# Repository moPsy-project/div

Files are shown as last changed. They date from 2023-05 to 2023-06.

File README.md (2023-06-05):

# DIV

> Simple Counter/Divider Eurorack Module

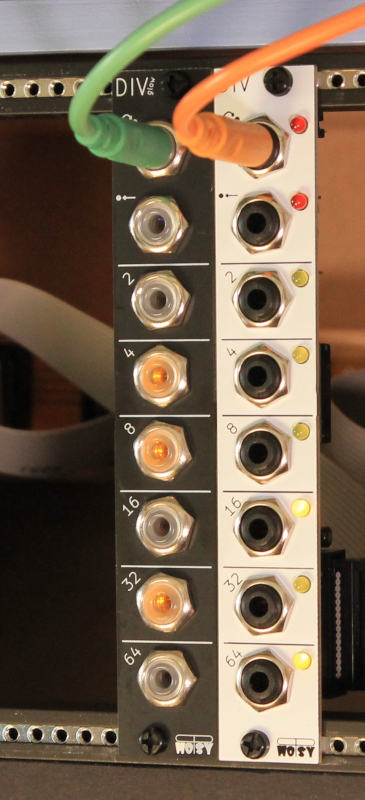
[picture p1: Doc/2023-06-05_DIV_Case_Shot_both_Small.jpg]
Front view of the DIV panel in a rack


## Dependencies

This project uses symbols from the [moPsy-KiCad-resources](https://github.com/moPsy-project/moPsy-KiCad-resources).

## License



This work is licensed under a [Creative Commons Attribution-ShareAlike 4.0 International License](http://creativecommons.org/licenses/by-sa/4.0/).

BY: Stefan Haun (mail@tuxathome.de)

See [LICENSE.txt](LICENSE.txt) for details.

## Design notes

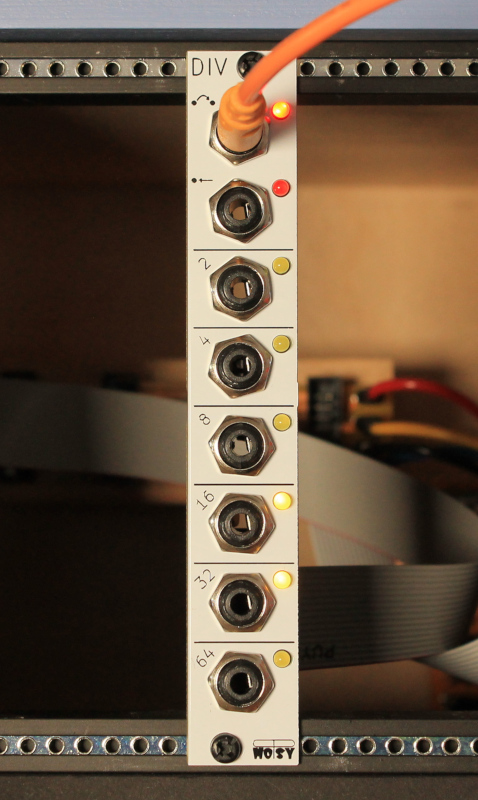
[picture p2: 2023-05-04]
Doc/2023-05-04_DIV_Case_Shot_Small.jpg

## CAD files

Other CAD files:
Frontpanel/div-outline.FCStd
Frontpanel/div-outline.dxf

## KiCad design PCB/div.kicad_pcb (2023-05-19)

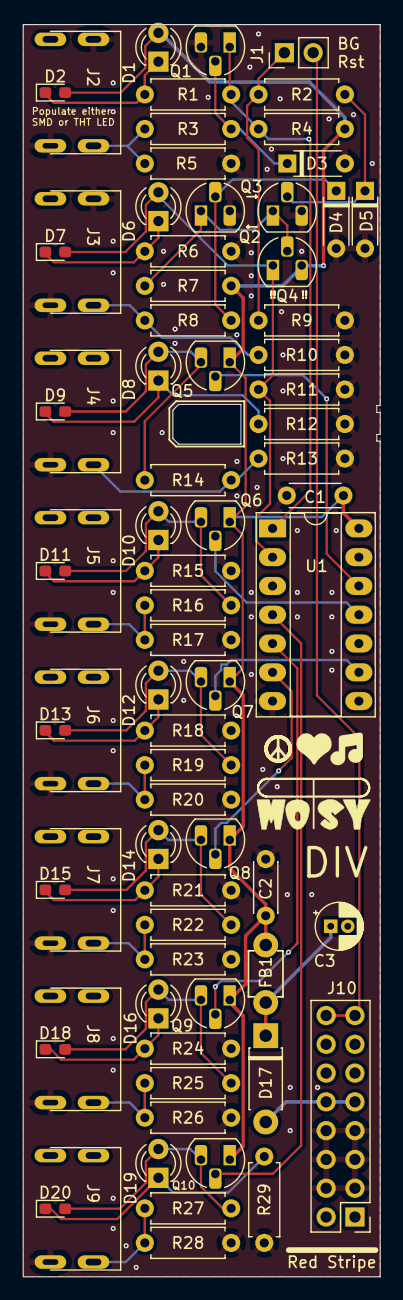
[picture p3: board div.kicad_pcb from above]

Board: 2 copper layers, 31.5 x 110.5 mm, 74 parts (0 on the bottom side), 40 nets.

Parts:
C1, C2: 100n; C_Disc_D4.3mm_W1.9mm_P5.00mm
C3: 10u; CP_Radial_D4.0mm_P1.50mm
D1: ye; LED_D3.0mm
D2, D7, D9, D11, D13, D15, D18, D20: gn; LED_0603_1608Metric_Pad1.05x0.95mm_HandSolder
D3, D4, D5: 1N4148; D_DO-35_SOD27_P5.08mm_Horizontal
D6: rt; LED_D3.0mm
D8, D10, D12, D14, D16, D19: gn; LED_D3.0mm
D17: 1N5817; D_DO-41_SOD81_P7.62mm_Horizontal
FB1: FerriteBead; FBeadL4D4
J1: Bus Gate Reset; PinHeader_1x02_P2.54mm_Vertical
J2: Clk; CLIFF 3.5mm S6 Mono Jack Socket
J3: Rst; CLIFF 3.5mm S6 Mono Jack Socket
J4, J5, J6, J7, J8, J9: OUT; CLIFF 3.5mm S6 Mono Jack Socket
J10: PWR; PinHeader_2x08_P2.54mm_Vertical
Q1, Q2, Q3, Q5, Q6, Q7, Q8, Q9, Q10: BC547; TO-92_HandSolder
Q4: BC557; TO-92_HandSolder
R1, R2, R3, R4, R6, R7, R8, R11, R12, R15, R18, R21, R24, R29: 10k; R_Axial_DIN0207_L6.3mm_D2.5mm_P7.62mm_Horizontal
R5, R9, R10: 1M; R_Axial_DIN0207_L6.3mm_D2.5mm_P7.62mm_Horizontal
R13, R14, R16, R17, R19, R20, R22, R23, R25, R26, R27, R28: 2k2; R_Axial_DIN0207_L6.3mm_D2.5mm_P7.62mm_Horizontal
U1: 4024; DIP-14_W7.62mm_Socket_LongPads

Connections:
+12V: C1.1, C2.1, D1.2 (A), D2.2 (A), FB1.2, Q4.3 (E), Q5.1 (C), Q6.1 (C), Q7.1 (C), Q8.1 (C), Q9.1 (C), Q10.1 (C), R4.2, R7.2, U1.14 (VDD)
/CLOCK_IN: Q1.1 (C), R1.1, R4.1, U1.1 (~CLK)
/Gate Output 2/GATE_OUT: Q5.2 (B), U1.12 (Q0)
/Gate Output 4/GATE_OUT: Q6.2 (B), U1.11 (Q1)
/Gate Output 8/GATE_OUT: Q7.2 (B), U1.9 (Q2)
/Gate Output 16/GATE_OUT: Q8.2 (B), U1.6 (Q3)
/Gate Output 32/GATE_OUT: Q9.2 (B), U1.5 (Q4)
/Gate Output 64/GATE_OUT: Q10.2 (B), U1.4 (Q5)
/RESET_IN: D6.2 (A), D7.2 (A), Q4.1 (C), R11.2, U1.2 (MR)
GND: C1.2, C2.2, C3.2, D3.2 (A), D4.2 (A), D5.2 (A), J2.S, J2.TN, J3.S, J3.TN, J4.S, J5.S, J6.S, J7.S, J8.S, J9.S, J10.3, J10.4, J10.5, J10.6, J10.7, J10.8, Q1.3 (E), Q2.3 (E), Q3.3 (E), R5.1, R6.1, R9.1, R10.1, R11.1, R12.1, R13.1, R15.1, R17.1, R18.1, R20.1, R21.1, R23.1, R24.1, R26.1, R28.1, R29.1, U1.7 (VSS)
Gate: J1.2, J10.15, J10.16
unnamed: D1.1 (K), D2.1 (K), R1.2
unnamed: D3.1 (K), Q1.2 (B), R3.2
unnamed: D4.1 (K), Q2.2 (B), R8.2
unnamed: D5.1 (K), Q3.2 (B), R2.2
unnamed: D6.1 (K), D7.1 (K), R6.2
unnamed: D8.2 (A), D9.2 (A), Q5.3 (E), R14.2
unnamed: D8.1 (K), D9.1 (K), R12.2
unnamed: D10.2 (A), D11.2 (A), Q6.3 (E), R16.2
unnamed: D10.1 (K), D11.1 (K), R15.2
unnamed: D12.2 (A), D13.2 (A), Q7.3 (E), R19.2
unnamed: D12.1 (K), D13.1 (K), R18.2
unnamed: D14.2 (A), D15.2 (A), Q8.3 (E), R22.2
unnamed: D14.1 (K), D15.1 (K), R21.2
unnamed: D16.2 (A), D18.2 (A), Q9.3 (E), R25.2
unnamed: D16.1 (K), D18.1 (K), R24.2
unnamed: D17.2 (A), J10.9, J10.10
unnamed: C3.1, D17.1 (K), FB1.1
unnamed: D19.2 (A), D20.2 (A), Q10.3 (E), R27.2
unnamed: D19.1 (K), D20.1 (K), R29.2
unnamed: J1.1, R2.1, R9.2
unnamed: J2.T, R3.1, R5.2
unnamed: J3.T, R8.1, R10.2
unnamed: J4.T, R13.2, R14.1
unnamed: J5.T, R16.1, R17.2
unnamed: J6.T, R19.1, R20.2
unnamed: J7.T, R22.1, R23.2
unnamed: J8.T, R25.1, R26.2
unnamed: J9.T, R27.1, R28.2
unnamed: Q2.1 (C), Q3.1 (C), Q4.2 (B), R7.1

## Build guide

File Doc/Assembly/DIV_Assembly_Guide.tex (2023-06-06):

\documentclass[a4paper,
               11pt,
               parskip=half,
               headinclude,
               titlepage=false]{scrartcl}

%%%%%%%%%%%%%%%%%%%%%%%%%%%%%%%%%%%%%%%%
\newcommand{\metaauthor}{moPsy}
\newcommand{\metatitle}{DIV Assembly Guide}
\newcommand{\metarev}{1.1}
%%%%%%%%%%%%%%%%%%%%%%%%%%%%%%%%%%%%%%%%

\usepackage[utf8]{inputenc}

\usepackage[T1]{fontenc}        % Tries to use Postscript Type 1 Fonts for better rendering
\usepackage{lmodern}            % Provides the Latin Modern Font which offers more glyphs than the default Computer Modern
\usepackage[sfdefault]{carlito}
\usepackage[intlimits]{amsmath} % Provides all mathematical commands
\usepackage[protrusion=true,
            expansion,
            kerning=true,
            babel=true]{microtype}
\usepackage{fontawesome}

\usepackage[english]{babel}
\usepackage[english]{isodate}

\usepackage{eurosym}
\usepackage[shortlabels]{enumitem}

\usepackage{grffile}            % Allow you to include images (like graphicx). Usage: \includegraphics{path/to/file}

\usepackage[ugly]{units}        % Allows you to type units with correct spacing and font style. Usage: $\unit[100]{m}$ or $\unitfrac[100]{m}{s}$

\usepackage{xspace}             % Use \xpsace in macros to automatically insert space based on context. Usage: \newcommand{\es}{ESPResSo\xspace}
\usepackage[dvipsnames,table]{xcolor}             % Obviously colors. Usage: \color{red} Red text
\usepackage{booktabs}           % Nice rules for tables. Usage \begin{tabular}\toprule ... \midrule ... \bottomrule

%\usepackage[hang]{subfigure}  % unterteilte Abbildungen
\usepackage{setspace}          %fuer dem Zeilanabstand
\usepackage[hang,bf,footnotesize]{caption}   % bessere Bildunterschriften
\usepackage{wrapfig}

\usepackage{csquotes}

\usepackage[hyphens]{url}                % Lets you typeset urls. Usage: \url{http://...}
\usepackage[pdftex,colorlinks=true,linkcolor=black,citecolor=black,urlcolor=black]{hyperref}
\hypersetup{
  pdftitle    = {\metatitle},
  pdfsubject  = {Assembly Guide},
  pdfauthor   = {\metaauthor},
  pdfkeywords = {} ,
  pdfcreator  = {pdflatex},
  pdfproducer = {LaTeX with hyperref}
}
%%%%%%%%%%%%%%%%%%%%%%%%%%%%%%%%%%%%%%%%

\usepackage{pdfpages}

\usepackage{tabularx}

\usepackage[headsepline, footsepline]{scrlayer-scrpage}
\setlength{\headheight}{34pt} % logo height
\clearpairofpagestyles
\ohead{
\vfill%
\begin{tabular}{@{}l l@{}}
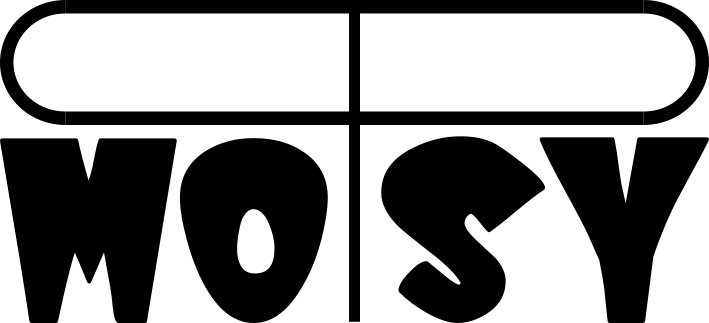
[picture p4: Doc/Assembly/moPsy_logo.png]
\hspace*{-0.1cm}
\end{tabular}
}
\ihead{
\vfill%
{\huge DIV} \,v\metarev\, Assembly Guide%
}
\ofoot{Page \thepage}
\setkomafont{pageheadfoot}{\sffamily\footnotesize}
\setkomafont{pagination}{}
\pagestyle{scrheadings}

%\usepackage{background}

%\usepackage[section]{placeins} % keep figures in their section

\definecolor{level_easy}{rgb}{0.2, 0.6, 0.1}

\definecolor{row1}{rgb}{1.0, 1.0, 1.0}
\definecolor{row2}{rgb}{0.93, 0.93, 0.99}

\begin{document}

\begin{minipage}{12.5cm}
\setlength{\parskip}{\medskipamount}
\section*{Thank you for choosing a  kit!}

\paragraph{tl;dr} Assembly is pretty straightforward. However, we strongly recommend soldering the transistors \emph{after} the LEDs to avoid Euclidean trouble.

This manual is meant to guide you through the assembly process.
We will point out common pitfalls when building this particular module.
Components are placed in an order that makes assembly as easy as possible.

The build is rated as {\color{level_easy}easy} and intended for {\color{level_easy}beginners}.
Still there may be bugs in the instructions or something may not be communicated optimally.
If you happen to get stuck or something is not clear, feel free to send us a message and we will do our best to sort things out.

You can reach us at \href{mailto:diy@mopsy-music.de}{\texttt{diy@mopsy-music.de}}.

Music is meant to be fun and we hope that you will enjoy building this module.
Please remember to take good care of yourself and get regular breaks whenever you start to feel exhausted. This is supposed to be an afternoon stroll, not a sprint for your life.

\vspace{1em}
Enjoy building! \quad 

\end{minipage}
\hspace{0.5cm}
\begin{minipage}{1.5cm}
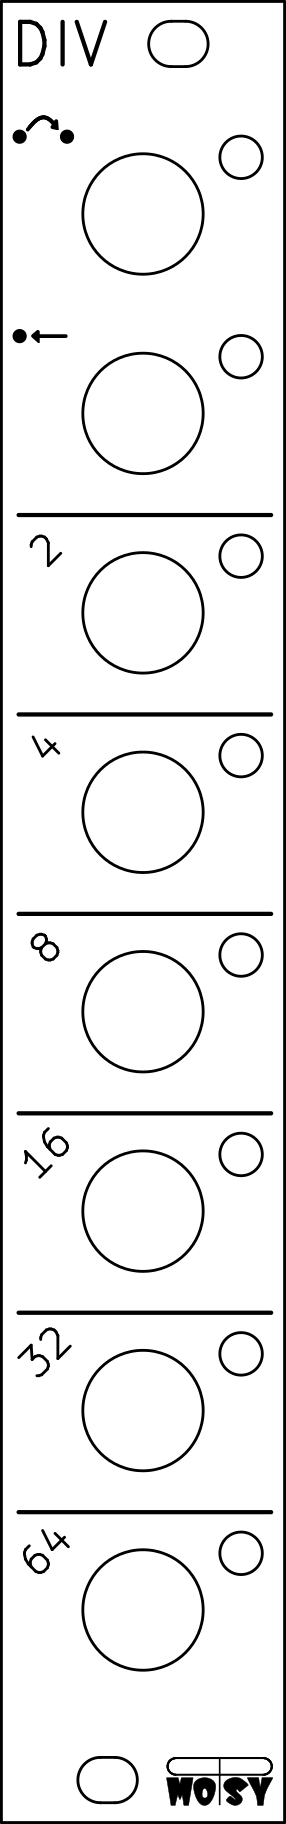
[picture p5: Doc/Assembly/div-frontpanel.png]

\end{minipage}

%\newpage
\subsection*{Resistors}

The resistors are color coded to identify their value. However, as these are sometimes hard to identify, we recommend using a multimeter to be sure.
Resistors do not have a polarity. Choosing a specific alignment is purely aesthetic.

\begin{tabularx}{\textwidth}{| r | l | X |}
\hline 
Qty & Value & Designator on PCB \\
\hline
14 & 
10k (brown, black, black, red, brown) & 
R1, R2, R3, R4, R6, R7, R8, R11, R12, R15, R18, R21, R24, R29 \\
\hline
12 &
2k2 (red, red, black, brown, brown) &
R13, R14, R16, R17, R19, R20, R22, R23, R25, R26, R27, R28 \\
\hline
3 &
1M (brown, black, black, yellow, brown) &
R5, R9, R10 \\
\hline  
\end{tabularx}

\subsection*{Diodes}

Diodes have a polarity! Please make sure that the black or white line on the diode matches with the line on the PCB.

\begin{tabularx}{\textwidth}{| r | l | X |}
\hline
Qty & Value & Designator on PCB \\
\hline
3 &
1N4148 (red) &
D3, D4, D5 \\
\hline
1 &
1N5817 (black) &
D17 \\
\hline
\end{tabularx}

\textbf{Please keep one of the legs of D17 for the ferrite beads!}

\subsection*{Ferrite Beads}

Use the leftover leg from D17 (above) to thread the ferrite bead and solder it like a resistor.

\begin{tabularx}{\textwidth}{| r |  X |}
\hline
Qty & Designator on PCB \\
\hline
1 &
FB1 \\
\hline
\end{tabularx}

\subsection*{IC and socket}

When placing the IC socket, please make sure that the notch is aligned with the notch on the PCB drawing. While the socket itself does not have an orientation, soldering it backwards will lead to confusion later.

Place the IC after the assembly of all components and take care of its orientation (notch or dot on the IC must match the notch on PCB and socket).

\begin{tabularx}{\textwidth}{| r | l | X |}
\hline
Qty & Value & Designator on PCB \\
\hline
1 &
4024 &
U1 \\
\hline
\end{tabularx}

\subsection*{Capacitors}

The ceramic capacitors (yellow) do not have a polarity and can be soldered in any orientation.
Have a look at \url{https://www.wikihow.com/Read-a-Capacitor} if you need help identifying capacitors.

\begin{tabularx}{\textwidth}{| r | l | X |}
\hline
Qty & Value & Designator on PCB \\
\hline
2 &
100n (Code 104) &
C1, C2 \\
\hline
\end{tabularx}

\subsection*{Electrolytic Capacitors}

Electrolytic capacitors \emph{do have a polarity} and are clearly marked with \texttt{+} or \texttt{-}. On the PCB, the white half of the marking is intended for the negative (\texttt{-}) side.

\begin{tabularx}{\textwidth}{| r | l | X |}
\hline
Qty & Value & Designator on PCB \\
\hline
1 &
10u (black) &
C3 \\
\hline
\end{tabularx}

\subsection*{Pin Headers}

Next up is the jumper for selecting the bus gate connection.

Solder the 2-pin header to J1.

When soldering, please make sure that the jumper sits straight on the PCB and does not lean out to the top. It may help to adjust while soldering the first pin. Be careful not to burn your fingers by not touching the part that you are currently soldering!

\subsection*{Mini Jacks}

Solder the eight mini jacks on J2 -- J9.

Please make sure they sit flush with the PCB, as they need to be aligned.
You can also put them in first, check with the front panel and then solder them.

Do not attach the front panel yet.

\subsection*{Power Connector}

Solder the power connector to J10.

Please make sure that the notch points to the edge of the PCB!

To make sure that the connector sits flush on the PCB, you can tag one pin first, then gently push the connector towards the PCBs and re-solder that pin. When you are happy with the alignment, solder the remaining pins (check again after the 2nd pin, after that, the position is fixed).

\subsection*{Front Panel}

Now it is time to assemble the front panel.
Just put it over the jacks and fix with the screws.

Please make sure that the orientation is correct, putting the clock input to the top (next to the Jumper) and the \enquote{64} output next to the power connector.

\subsection*{LEDs}

The LEDs are a bit tricky, but you have got help! 

If you turn the PCB over, there is a pending gauge to help with getting the lead lengths right: Place the LED into the hole so that the legs cover the lines on the PCB. 

Please make sure that the polarity is correct. The short leg (cathode) matches the \enquote{K} line, the long leg (anode) matches the \enquote{A} line.

When you are content with the LED alignment, bend the legs 90 degrees on the PCB edge.

Place the LED into its respective position on the PCB and its matching hole in the panel. When everything is aligned (short leg, i.e. cathode, to the square pad), solder the LED to the PCB.

We recommend fitting and soldering each LED individually.

\begin{tabularx}{\textwidth}{| r | l | X |}
\hline
Qty & Color & Designator on PCB \\
\hline
2 &
red &
D1, D6 \\
\hline
6 &
yellow &
D8, D10, D12, D14, D16, D19 \\
\hline
\end{tabularx}

\subsection*{Transistors}

Finally, solder the transistors. These have been left until now to make LED assembly easier.

With tweezers gently bend the center leg towards the round side of the package, then bend back until the legs are parallel again and match the footprint.

The transistors do not sit flush on the PCB, but hover a bit above it. Please do not apply too much force when pushing them in, as this may stress and break the package.
For nice alignment, it helps to solder the middle leg (base) first, then align the part and solder the other two legs.

\begin{tabularx}{\textwidth}{| r | l | X |}
\hline
Qty & Value & Designator on PCB \\
\hline
1 &
BC557 &
Q4 \\
\hline
9 &
BC547 &
Q1, Q2, Q3, Q5, Q6, Q7, Q8, Q9, Q10 \\
\hline
\end{tabularx}

\subsection*{IC}

Place the IC into its socket. It may help to carefully bend the legs on a flat surface.
Please make sure that the direction marks on the IC and the socket match (see also above).

\vspace{0.5cm}
\begin{center}
Enjoy your new module! \quad 
\end{center}

\newpage

\section*{Silk Screen / Component Placement}
\begin{center}
\begin{minipage}{.35\linewidth}
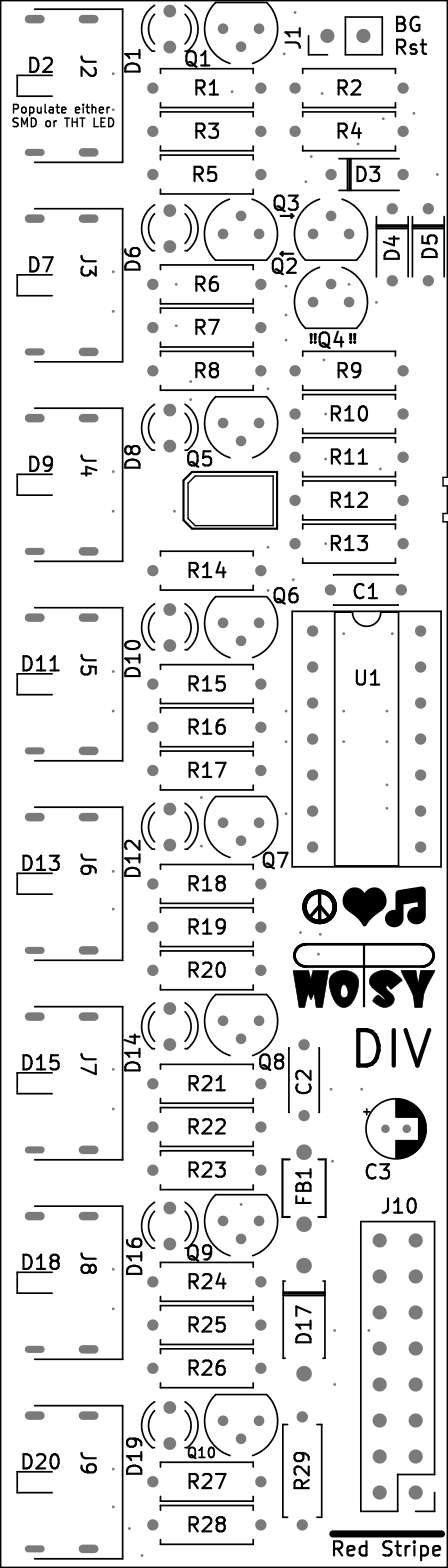
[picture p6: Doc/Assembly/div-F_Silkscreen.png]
  
\end{minipage}
\hspace{.1\linewidth}
\begin{minipage}{.35\linewidth}
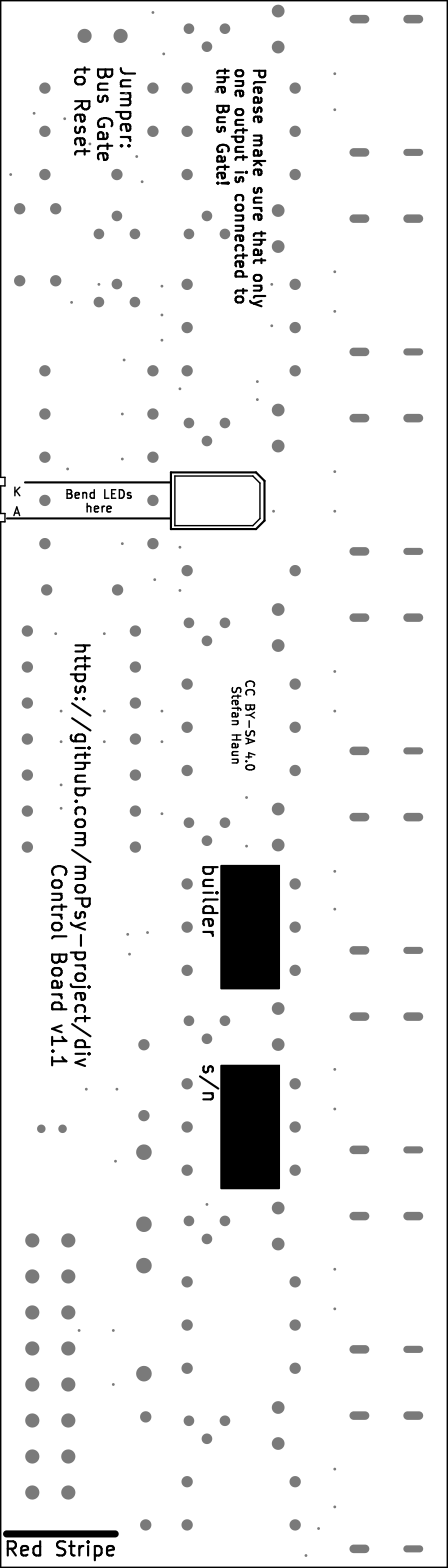
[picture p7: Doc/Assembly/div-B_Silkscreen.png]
  
\end{minipage}
\end{center}

\newpage

\section*{Assembly Variants}

If you just want to build the kit, please ignore this section.

There are three ways in which you may want to deviate from the build instructions, which are described below.
Please note that we do not provide the necessary parts to implement these changes with our kits. 

\subsection*{DIV Glow}

The \emph{DIV glow} variant uses SMD LEDs and transparent jacks instead of separate panel LEDs. The changes are:
\begin{itemize}[noitemsep]
 \item Populate D2, D7, D9, D11, D13, D15, D18, D20 with 0604in-sized LEDs. We recommend using extra bright LEDs (around \unit[200]{mcd}), especially if you do not want to tweak the LED resistors. 
 \item DO NOT populate D1, D6, D8, D10, D12, D14, D16, D19.
 \item Adjust the LED resistors accordingly (see below).
 \item We recommend using the \emph{DIV glow} panel.
\end{itemize}

\subsection*{LED resistors}

To tweak the LED brightness or if you are not using extra bright LEDs (around \unit[200]{mcd}), you can adjust the LED resistors accordingly.

From top to bottom on the panel, these are: R1, R6, R12, R15, R18, R21, R24, R29.

Please note that the power ratings change with these LEDs and the module might source much more current than expected.

We strongly recommend sticking to extra bright LEDs. However, lowering the LED resistors to 4k7 might improve your experience while staying within an acceptable power consumption.

\subsection*{No Bus Reset}

You can leave out the Bus reset feature. The components involved are so cheap that we only recommend this step if there is a real reason. (Please let us know when this happens!)

To skip the bus access, do not populate these components: R2, R9, D5, Q3, J1

\end{document}

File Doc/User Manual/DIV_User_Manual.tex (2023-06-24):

\documentclass[a4paper,
               11pt,
               parskip=half,
               headinclude,
               titlepage=false]{scrartcl}

%%%%%%%%%%%%%%%%%%%%%%%%%%%%%%%%%%%%%%%%
\newcommand{\metaauthor}{moPsy}
\newcommand{\metatitle}{DIV User Manual}
\newcommand{\metarev}{1.1}
%%%%%%%%%%%%%%%%%%%%%%%%%%%%%%%%%%%%%%%%

\usepackage[utf8]{inputenc}

\usepackage[T1]{fontenc}        % Tries to use Postscript Type 1 Fonts for better rendering
\usepackage{lmodern}            % Provides the Latin Modern Font which offers more glyphs than the default Computer Modern
\usepackage[sfdefault]{carlito}
\usepackage[intlimits]{amsmath} % Provides all mathematical commands
\usepackage[protrusion=true,
            expansion,
            kerning=true,
            babel=true]{microtype}
\usepackage{fontawesome}

\usepackage[english]{babel}
\usepackage[english]{isodate}

\usepackage{eurosym}
\usepackage[shortlabels]{enumitem}

\usepackage{grffile}            % Allow you to include images (like graphicx). Usage: \includegraphics{path/to/file}

\usepackage[ugly]{units}        % Allows you to type units with correct spacing and font style. Usage: $\unit[100]{m}$ or $\unitfrac[100]{m}{s}$

\usepackage{xspace}             % Use \xpsace in macros to automatically insert space based on context. Usage: \newcommand{\es}{ESPResSo\xspace}
\usepackage[dvipsnames,table]{xcolor}             % Obviously colors. Usage: \color{red} Red text
\usepackage{booktabs}           % Nice rules for tables. Usage \begin{tabular}\toprule ... \midrule ... \bottomrule

%\usepackage[hang]{subfigure}  % unterteilte Abbildungen
\usepackage{setspace}          %fuer dem Zeilanabstand
\usepackage[hang,bf,footnotesize]{caption}   % bessere Bildunterschriften
\usepackage{wrapfig}

\usepackage{csquotes}

\usepackage[hyphens]{url}                % Lets you typeset urls. Usage: \url{http://...}
\usepackage[pdftex,colorlinks=true,linkcolor=black,citecolor=black,urlcolor=black]{hyperref}
\hypersetup{
  pdftitle    = {\metatitle},
  pdfsubject  = {Assembly Guide},
  pdfauthor   = {\metaauthor},
  pdfkeywords = {} ,
  pdfcreator  = {pdflatex},
  pdfproducer = {LaTeX with hyperref}
}
%%%%%%%%%%%%%%%%%%%%%%%%%%%%%%%%%%%%%%%%

\usepackage{pdfpages}

\usepackage{tabularx}

\usepackage[headsepline, footsepline]{scrlayer-scrpage}
\setlength{\headheight}{34pt} % logo height
\clearpairofpagestyles
\ohead{
\vfill%
\begin{tabular}{@{}l l@{}}
\hspace*{-0.1cm}
\end{tabular}
}
\ihead{
\vfill%
{\huge DIV} \,v\metarev\, User Manual%
}
\ofoot{Page \thepage}
\setkomafont{pageheadfoot}{\sffamily\footnotesize}
\setkomafont{pagination}{}
\pagestyle{scrheadings}

%\usepackage{background}

%\usepackage[section]{placeins} % keep figures in their section

\definecolor{level_easy}{rgb}{0.2, 0.6, 0.1}

\definecolor{row1}{rgb}{1.0, 1.0, 1.0}
\definecolor{row2}{rgb}{0.93, 0.93, 0.99}

\begin{document}

\begin{minipage}[]{10.5cm}
\setlength{\parskip}{\medskipamount}
\section*{Thank you for choosing a  module!}

This manual provides information on installing and using the DIV module.
We hope that all questions will be answered.
If you encounter a problem or have further questions,
please do not hesitate to reach us at \href{mailto:contact@mopsy-music.de}{\texttt{contact@mopsy-music.de}}.

\vspace{1em}
\begin{center}
Enjoy your module! \quad 
\end{center}

\section*{About DIV}

\emph{DIV} is a rhythm and clock divider with six output stages, similar to the Doepfer \href{https://doepfer.de/a160.htm}{Doepfer A-160-1}.

It accepts audio frequencies and happily scales them down by several octaves. (Bear in mind that the output will be 50\% PWM.)

The reset input can be configured to trigger from the bus gate with a jumper.

\end{minipage}%
\hspace{0.5cm}
\begin{minipage}[]{4cm}
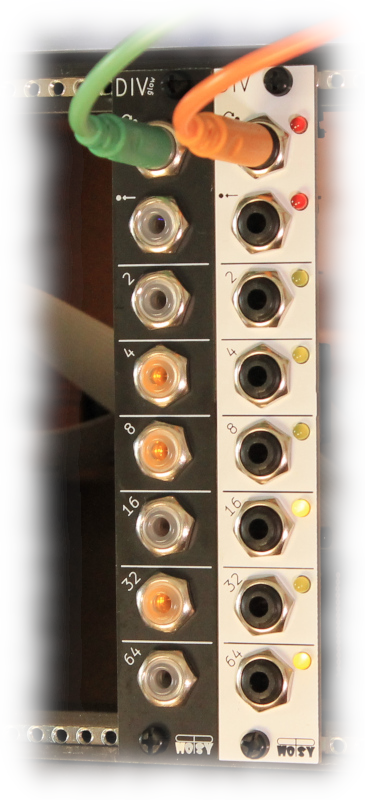
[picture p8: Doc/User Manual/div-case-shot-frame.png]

\end{minipage}

\section*{Installation}

The DIV module will occupy \textbf{\unit[4]{HP}} in your rack with a depth of \textbf{\unit[40]{mm}}.

To \textbf{connect power} …
\begin{enumerate}
 \item Please make sure that your cabinet is \textbf{disconnected from the mains} and has no power.
 \item The module is connected with a \textbf{16-pin} (2x8) bus cable.
 \item \textbf{Check your power cable and the polarity.} The coloured ({\color{red}red}) line on the cable (pin 1) needs to be connected to the \textbf{\unit[-12]{V}} rail.
 If the module is installed in an upright orientation, the \textbf{\color{red}red stripe} needs to be \textbf{facing down}.
 \item If you plug the module backwards, it may burn out.
 Unfortunately this cannot be covered by the warranty.
\end{enumerate}

The module draws a maximum of \textbf{\unit[40]mA} from the \textbf{\unit[+12]{V}} rail.

\begin{minipage}[]{4cm}
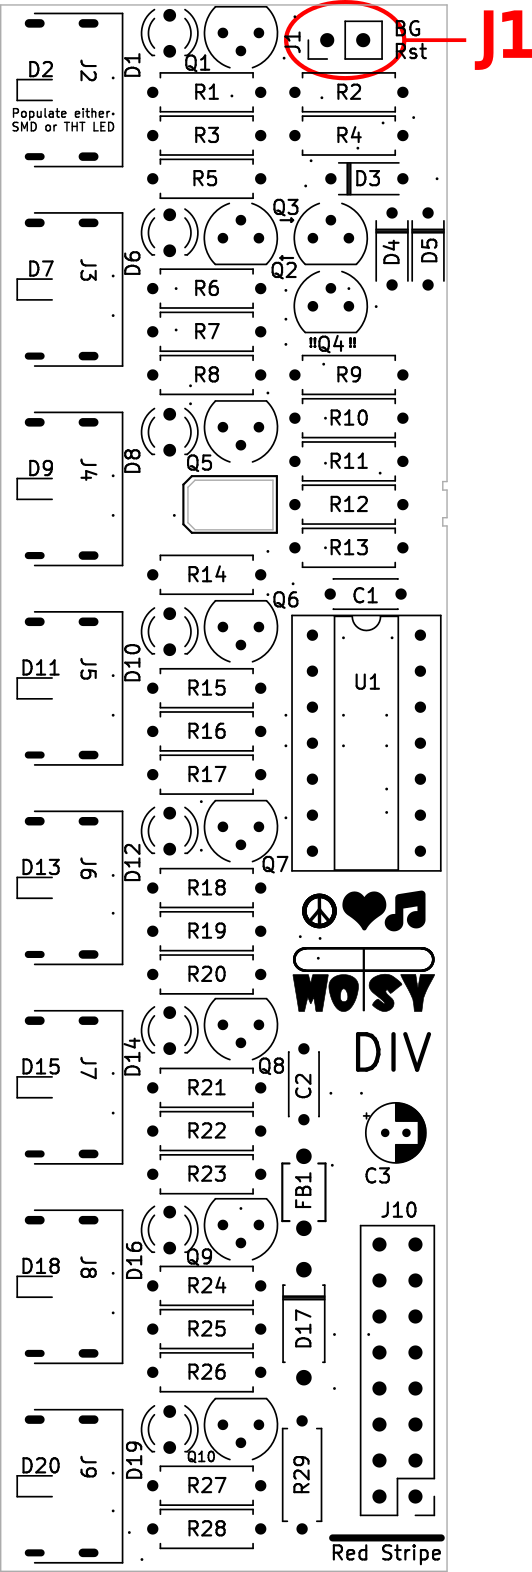
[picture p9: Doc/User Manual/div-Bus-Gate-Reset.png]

\end{minipage}
\hspace{0.5cm}
\begin{minipage}[]{10.5cm}
\setlength{\parskip}{\medskipamount}

\section*{Setup}

Jumper \textbf{\color{red}J1} connects the module's reset to the Bus Gate, allowing for a global reset signal.

Set this jumper if you want to use the feature, otherwise we propose to just leave it on one pin of the header so that it will be available for later use.

\end{minipage}

\begin{minipage}[]{10.5cm}
\setlength{\parskip}{\medskipamount}
\section*{Frontpanel}

The \textbf{\color{red}Clock Input} advances the counter by one step on each rising edge.
Gates can also be applied, however only rising edges will have an effect.

The frequency can go well into the audible range.

If the module does not react, either the frequency is too high and an edge can no longer be detected, or the signal voltage is too low.

\vspace{1em}

On a rising edge (trigger) the \textbf{\color{red}Reset Input} will set the internal counter to zero and switch all outputs off.
The counter is blocked if this input held high (gated).

The Reset Input is mirrored on the bus side (see \emph{Setup}) with the same behavior. Both inputs can be used simultaneously.% and are OR'ed together.

\vspace{1em}

The \textbf{\color{red}Divider Output} gates are a binary representation of the internal counter. They can also be understood as divisions by the number printed next to the output.

If the internal counter reaches its capacity of 64 steps it wraps around and restarts at zero.

\end{minipage}%
\hspace{0.5cm}
\begin{minipage}[]{4cm}
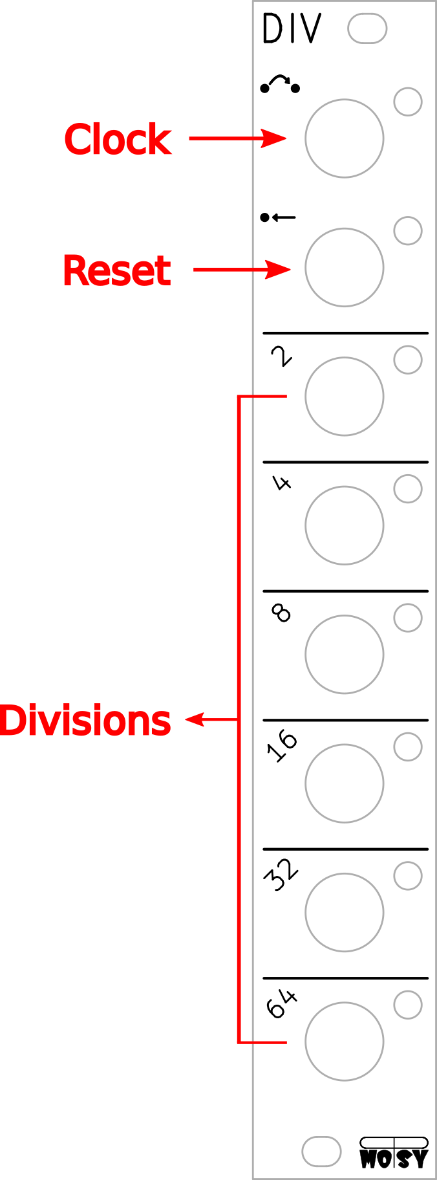
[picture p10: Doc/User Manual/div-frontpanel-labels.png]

\end{minipage}

\section*{Online Resources}

More about the module  …
\begin{itemize}[noitemsep]
 \item on our website: \url{https://www.mopsy-music.de/modules/div}
 \item via e-mail: \href{mailto:contact@mopsy-music.de}{\texttt{contact@mopsy-music.de}}
\end{itemize}

\end{document}

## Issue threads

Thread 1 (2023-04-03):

Verify the schematic

penguineer, 2023-04-03:
- [x] Counter behaviour
- [x] Output levels
- [x] Power strain on the IC
- [x] Reset does not back-drive the bus gate
- [x] Reset does in fact reset the IC (i.e. reaches the necessary voltage level)

penguineer, 2023-04-13:
Findings so far:
* LEDs are better driven with 4k7, otherwise they are too bright.
* Output transistors are in emitter follower configuration, thus only deliver Vcc-0.7V, which is too low for trigger outputs.

penguineer, 2023-04-14:
After mergin #8 all checks have to be repeated.

penguineer, 2023-04-18:
The output transistor base allows 11µA current, which does not exceed the maximum rating at all.

penguineer, 2023-04-18:
Counting and reset behaviour have been tested for Q0 and Q1 and are as expected. The remaining four outputs (Q2 to Q5) are expected to behave as well.

penguineer, 2023-04-18:
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

penguineer, 2023-04-18:
The above points have been tested and verified. I am confident that the module will work with this schematic.

Closed 2023-04-18.

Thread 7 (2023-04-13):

:bug: Emitter follower in output can never reach 5V

penguineer, 2023-04-13:
The emitter follower circuit in the gate outputs can never reach 5V (always Vcc-0.7V) and should be replaced by a different solution that allows to pass the +5V supply voltage.

penguineer, 2023-04-13:
Maybe try [2N 7000](http://www.reichelt.de/index.html?ARTICLE=41141) - MOSFET, N-CH, 60V, 0,115A, 0,4W, TO-92 ?

penguineer, 2023-04-13:
Alternatively use 12V?

penguineer, 2023-04-14:
> Maybe try [2N 7000](http://www.reichelt.de/index.html?ARTICLE=41141) - MOSFET, N-CH, 60V, 0,115A, 0,4W, TO-92 ?

Simluations show that at these voltages available MOSFETs also do not reach the desired voltage.

Closed 2023-04-14.

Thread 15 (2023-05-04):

:wrench: Adjust resistors  for less sensitivity

penguineer, 2023-05-04:
The inputs are very sensitive and react even to touch by a finger on the other end of the patch cable.

Adjust the resistor values to make the inputs a little less sensitive.

penguineer, 2023-05-05:
Resistor values have been adjusted in #20.

These are the only changes that can be made without changing the PCB layout, which is already fixed. Anything else needs to be moved to v1.1

Closed 2023-05-16.

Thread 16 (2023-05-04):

:art: Switch to a transistor footprint that is easier to solder

penguineer, 2023-05-04:
The current transistor footprint is very hard to solder because the pads are small and very close to each other.

Switch to a transistor footprint that allows for easier and more robust soldering.

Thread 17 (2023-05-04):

:art: Add a bending gauge for the front panel LEDs

penguineer, 2023-05-04:
It is a bit fiddly to the the front panel LEDs bent at the correct length.

Try to integrate a bending gauge into the PCB for easier assembly.

Closed 2023-05-16.

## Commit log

2023-04-03 :see_no_evil: Add gitignore for KiCAD projects
2023-04-03 :tada: Add KiCAD PCB project
    [the-count.kicad_pcb, the-count.kicad_sch]
2023-04-03 :sparkles: Add Power connection
    [the-count.kicad_sch]
2023-04-03 :sparkles: Add Gate output element
    [gate_output.kicad_sch, the-count.kicad_sch]
2023-04-03 :sparkles: Add count and reset input
    [the-count.kicad_sch]
2023-04-03 :sparkles: Add the counter logic
    [gate_output.kicad_sch, the-count.kicad_sch]
2023-04-03 :sparkles: Add bus gate reset option
    [the-count.kicad_sch]
2023-04-07 :wrench: Add moPsy footprint library
2023-04-07 :wrench: Set CLIFF footprints for the jacks
    [gate_output.kicad_sch, the-count.kicad_sch]
2023-04-07 :truck: Rename KiCad project to "div"
    [div.kicad_pcb, div.kicad_sch]
2023-04-07 :wrench: Adjust project name on sheets
    [div.kicad_sch, gate_output.kicad_sch]
2023-04-07 :sparkles: Add an outline sketch for the frontpanel
    [div-outline.FCStd]
2023-04-07 :bento: Export outline to DXF
    [div-outline.dxf]
2023-04-07 :sparkles: Add the non-text print for the frontpanel
2023-04-07 :sparkles: Add the frontpanel PCB with LED holes
    [div-pcb-leds.kicad_pcb]
2023-04-07 :sparkles: Add the frontpanel PCB without LED holes
    [div-pcb-no-leds.kicad_pcb]
2023-04-13 :bug: Fix reset input circuit
    [div.kicad_sch]
2023-04-13 :wrench: Adjust LED series resistors
    With 4k7 the brightness is much better to look at.
    [div.kicad_sch, gate_output.kicad_sch]
2023-04-14 :hammer: Switch circuit to 12V supply
    [div.kicad_sch]
2023-04-14 :hammer: Change output gate for 12V
    Add a resistor divider to create about 5V for the gate output.
    [gate_output.kicad_sch]
2023-04-18 :art: Improve reset input to drive 12V
    [div.kicad_sch]
2023-04-18 :art: Remove base resistor from output stage
    The emitter follower does not need a base resistor.
    Current has been measured at 11µA if the output is shorted to ground.
    [gate_output.kicad_sch]
2023-04-18 :art: Add separate transistor stage for the bus reset input
    This resolves the problems of backdriving and unwanted resistor
    dividers between jack and bus input.
    [div.kicad_sch]
2023-04-18 :pencil2: Fix naming of ferrite bead footprint
    [div.kicad_sch]
2023-04-18 :sparkles: Add symbol annotations
    [div.kicad_sch, gate_output.kicad_sch]
2023-04-18 :hammer: Optimize schematic for PCB layout
    [div.kicad_sch, gate_output.kicad_sch]
2023-04-18 :sparkles: Add first PCB layout
    [div.kicad_pcb]
2023-04-20 :sparkles: Add jack LEDs to the schematic
    Using clear jacks the LEDs can be put underneath them. The control
    PCB can support both versions (LEDs separate or in jacks), so a
    second (SMD) LED is added to the schematic.
    Only one of these may be populated!
    [div.kicad_sch, gate_output.kicad_sch]
2023-04-20 :sparkles: Add SMD LEDs to PCB
    [div.kicad_pcb]
2023-04-20 :hammer: Change power connector footprint in schematic
    [div.kicad_sch]
2023-04-20 :hammer: Adapt PCB to vertical header and turn red stripe down
    [div.kicad_pcb]
2023-04-20 :art: Leave more room around the power connector
    This is needed for the box header.
    [div.kicad_pcb]
2023-05-04 :hammer: Extend frontpanel copper layer to front and back side
    [div-pcb-leds.kicad_pcb]
2023-05-05 :wrench: Adjust output resistor divider
    Give a bit more driving power to the outputs by lowering the output
    resistor divider.
    This results in a current of 2.7mA through the resistor divider
    or 5.5mA in case of a short circuit.
    With all outputs switched on, consumption is 16.3mA
    (32.7mA short ciruit).
    [gate_output.kicad_sch]
2023-05-05 :wrench: Increase input resistors to improve impedance
    Set the input resistors to 100K to improve input impedance.
    [div.kicad_sch]
2023-05-16 :bento: Update PCB to set correct resistor values
    In #20 the resistor values have been changed in the schematic.
    As this was no PCB change, I did not mind to update the PCB file. However,
    the old resistor values are now shown there and also in the BOM.
    This is only an update to the resistor values stored in the PCB file, no changes
    to the actual PCB layout have been made.
    [div.kicad_pcb]
2023-05-16 :wrench: Change transistor footprint to handsolder version
    [div.kicad_sch, gate_output.kicad_sch]
2023-05-16 :wrench: Adjust PCB to changed transistor footprint
    [div.kicad_pcb]
2023-05-16 :sparkles: Add an LED bending gauge
    Allows to bend the LEDs exactly while building the module.
    [div.kicad_pcb]
2023-05-16 :art: Add a pull-down resistor to open bus gate reset
    If the jumper is not set, the bus gate reset would be floating. Add a
    (very large) pull-down resistor to keep this at GND.
    [div.kicad_pcb, div.kicad_sch]
2023-05-16 :art: Add a pull-down resistor to the reset input
    Attaching a cable and touching the other end triggers the reset.
    Add a (very large) pull-down resistor to prevent the line from
    floating.
    [div.kicad_pcb, div.kicad_sch]
2023-05-16 :art: Add a pull-down resistor to the clock input
    Keep this input from floating when only one end of the patch cable
    is connected by adding a (very large) pull-down resistor.
    [div.kicad_pcb, div.kicad_sch]
2023-05-16 :memo: Update sheet meta-data for revision 1.1
    [div.kicad_pcb, div.kicad_sch, gate_output.kicad_sch]
2023-05-16 :memo: Change PCB text to v1.1
    [div.kicad_pcb]
2023-05-16 :art: Change the diode footprint to make soldering easier
    [div.kicad_pcb, div.kicad_sch]
2023-05-16 :art: Move C1 slightly for a more relaxed fit with the power connector
    [div.kicad_pcb]
2023-05-16 :lipstick: Duplicate the "Red Stripe" marker to the bottom silk screen
    The front marker might be covered by the socket.
    [div.kicad_pcb]
2023-05-16 :lipstick: Fix designator positions for Q9 and Q10
    [div.kicad_pcb]
2023-05-16 :pencil2: Fix relevant DRC warnings
    [div.kicad_pcb]
2023-05-16 :adhesive_bandaid: Fix DRC errors
    Display of errors was accidentally switched off und with the change
    of transistor footprints trace overlaps have been introduced.
    These errors are now fixed.
    [div.kicad_pcb]
2023-05-16 :lipstick: Perform a Geographical Reannotation on the PCB
    [div.kicad_pcb, div.kicad_sch, gate_output.kicad_sch]
2023-05-16 :lipstick: Fix designator positions
    Some designators changed size as the number of digits changed.
    Fix their positions to avoid overlaps and ensure readability.
    [div.kicad_pcb]
2023-05-16 :sparkles: Add text areas for builder and S/N
    [div.kicad_pcb]
2023-05-16 :lipstick: Unify positions of diode designators
    [div.kicad_pcb]
2023-05-16 :adhesive_bandage: Fix direction of LED gauge
    [div.kicad_pcb]
2023-05-17 :wrench: Revert input resistors to 10K
    Test built with SMD LEDs shows that the 100K base resistor does not
    open the transistors sufficiently. Change back to 10K for robust
    operation.
    The problem that occurred: With lower LED series resistors (220R) the
    transistor would be part of a voltage divider leading to 6V output,
    which is not enough to trigger the 4024 clock input.
    [div.kicad_pcb, div.kicad_sch]
2023-05-17 :lipstick: Re-arrange logos
    [div.kicad_pcb]
2023-05-17 :lipstick: Change color of non-LED board and add "glow"
    [div-pcb-no-leds.kicad_pcb]
2023-05-17 :memo: Change frontpanel release to v1.1
    [div-pcb-leds.kicad_pcb, div-pcb-no-leds.kicad_pcb]
2023-05-19 :wrench: Change LED footprint to 0603
    This is harder to solder, but matching LEDs with 180mcd are available:
    * https://www.reichelt.de/led-smd-1608-0603-rot-180-mcd-120--led-el-0603-rt-p156256.html
    * https://www.reichelt.de/led-smd-1608-0603-gelb-180-mcd-120--led-el-0603-ge-p156259.html
    [div.kicad_pcb, div.kicad_sch, gate_output.kicad_sch]
2023-06-05 :bento: Add picture of case shot with DIV glow variant
2023-06-06 :sparkles: Add the assembly guide (tex)
2023-06-06 :art: Write resistor value consistent with other values
2023-06-06 :bento: Add case shot with frame
2023-06-06 :bento: Add silkscreen SVG exports
    PNG file are just exports of these. Add the SVG files to make later changes easier
2023-06-06 :pencil2: Fix change aspect number in assembly guide
    "two" → "three"

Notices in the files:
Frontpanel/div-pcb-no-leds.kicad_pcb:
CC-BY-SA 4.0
